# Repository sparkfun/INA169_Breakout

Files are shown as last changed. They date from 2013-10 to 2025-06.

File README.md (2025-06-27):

SparkFun INA169 Current Sensing Breakout
===============

[INA169 Current Sense Breakout Board  
*INA169 Current Sense Breakout Board (SEN-12040)*](https://www.sparkfun.com/products/12040)

High-side current sense breakout board. [The datasheet can be found here.](http://www.ti.com/lit/ds/symlink/ina169.pdf)

This part was created in Eagle v6.0.0. Example sketches were created in Arduino v1.0.5.

Repository Contents
-------------------

* **/Firmware** - Example Arduino sketches
* **/Hardware** - All Eagle design files (.brd, .sch, .STL)
* **/Production** - Test bed files and production panel files

Documentation
-------------------
* **[Hookup Guide](https://learn.sparkfun.com/tutorials/ina169-breakout-board-hookup-guide)**

Version History
---------------
* **v1.0** Initial release

License Information
-------------------
The hardware is released under [Creative Commons Share-alike 3.0](http://creativecommons.org/licenses/by-sa/3.0/).  
All other code is open source so please feel free to do anything you want with it; you buy me a beer if you use this and we meet someday ([Beerware license](http://en.wikipedia.org/wiki/Beerware)).

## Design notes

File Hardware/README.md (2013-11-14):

# What Are these Files?

The .sch and .brd files hare are Eagle CAD schematic and PCB design files.

These files were created with Eagle 6.0.0, you'll need Eagle 6.0 or later to open them up. There is a free, lite, version of Eagle available from [cadsoftusa.com](cadsoftusa.com).

# License

This product is open source! These Eagle files are released under the Creative Commons Share-Alike Attribution license ([CC BY-SA 3.0](http://creativecommons.org/licenses/by-sa/3.0/us/)).

Please use, reuse, and modify these files as you see fit. Please maintain attribution and release anything derivative under the same license.

- Your friends at SparkFun.

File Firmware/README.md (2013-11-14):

* INA169_Arduino_Example - Simple sketch showing how to use the INA169 to measure current through an LED

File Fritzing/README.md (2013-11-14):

* Fritzing diagram showing the INA169 Breakout Board connected to an [Arduino Uno](https://www.sparkfun.com/products/11021)
* The subfolder contains the source files for Fritzing diagrams for the INA169 Breakout Board.

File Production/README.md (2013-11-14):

These are the production files SparkFun uses for printing PCBs, as well as the Eagle files for our test beds.

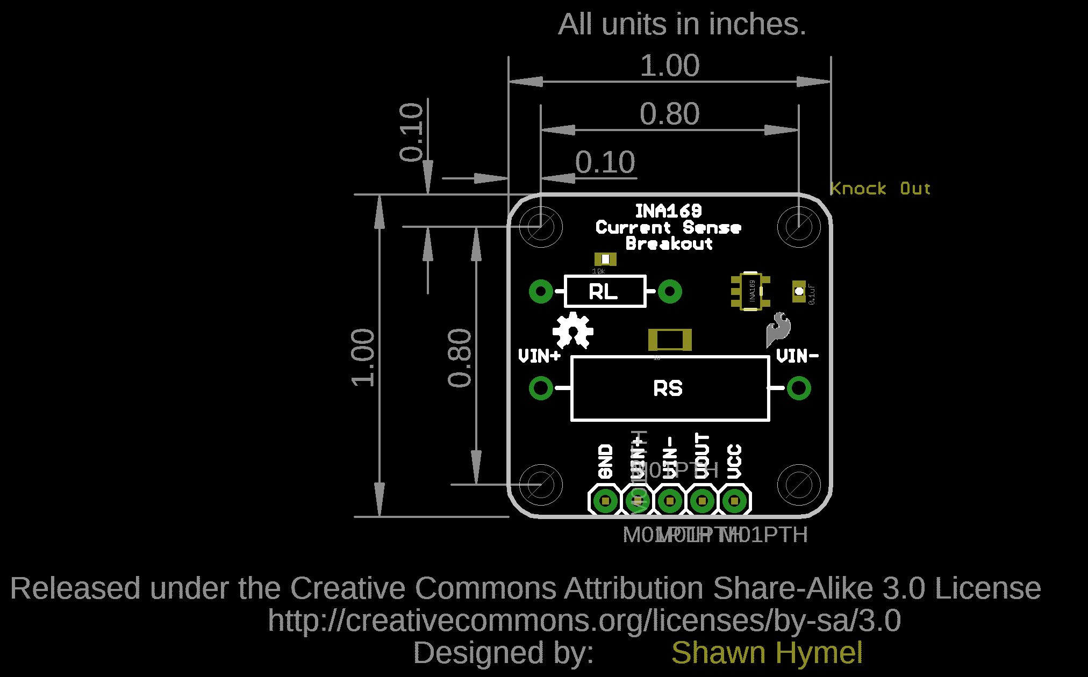
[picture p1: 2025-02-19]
Hardware/SEN-12040_INA169_Current_Sense_Breakout_Board_Dimensions.png

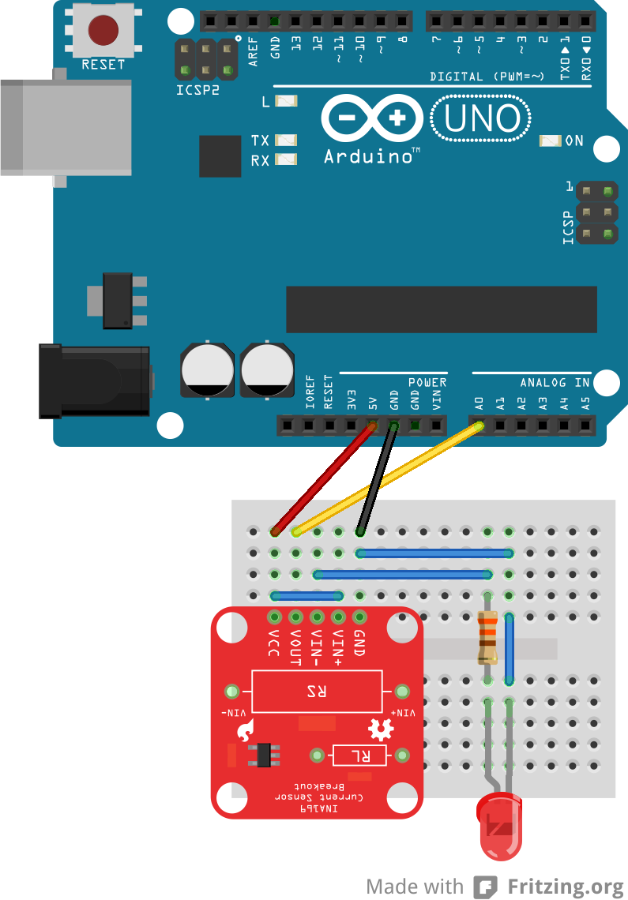
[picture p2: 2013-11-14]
Fritzing/INA169_Arduino_Example.png

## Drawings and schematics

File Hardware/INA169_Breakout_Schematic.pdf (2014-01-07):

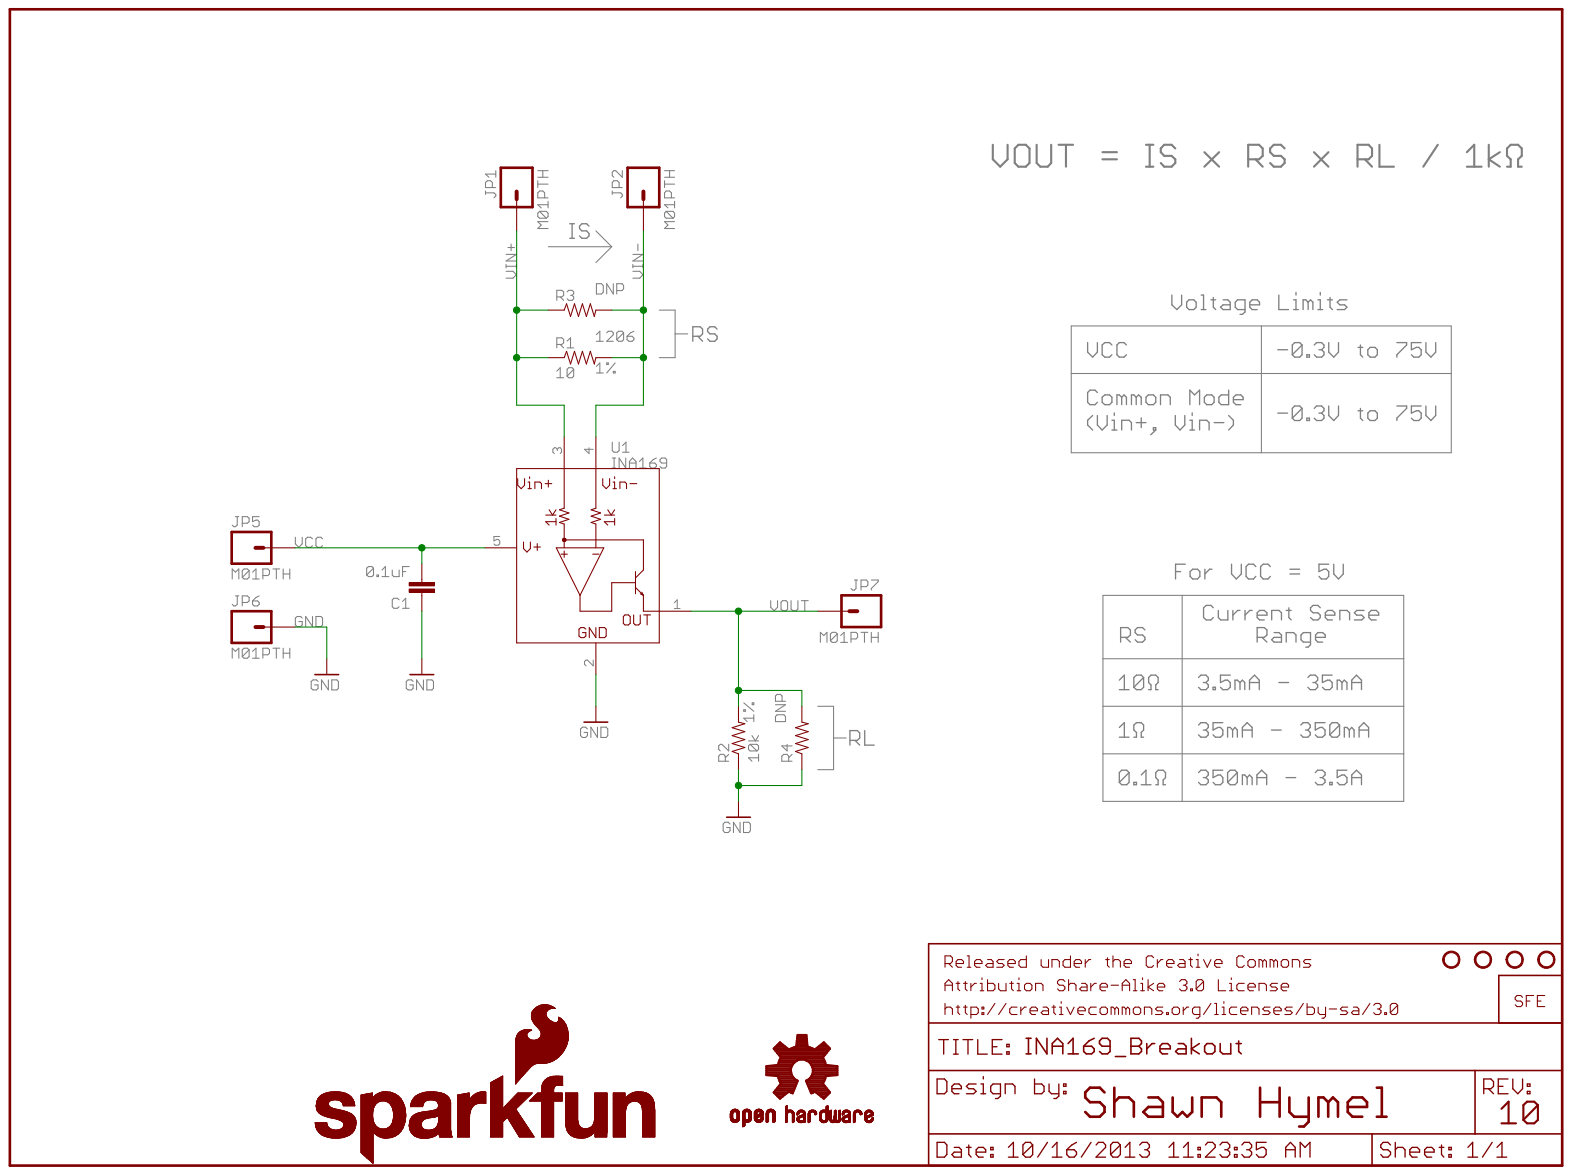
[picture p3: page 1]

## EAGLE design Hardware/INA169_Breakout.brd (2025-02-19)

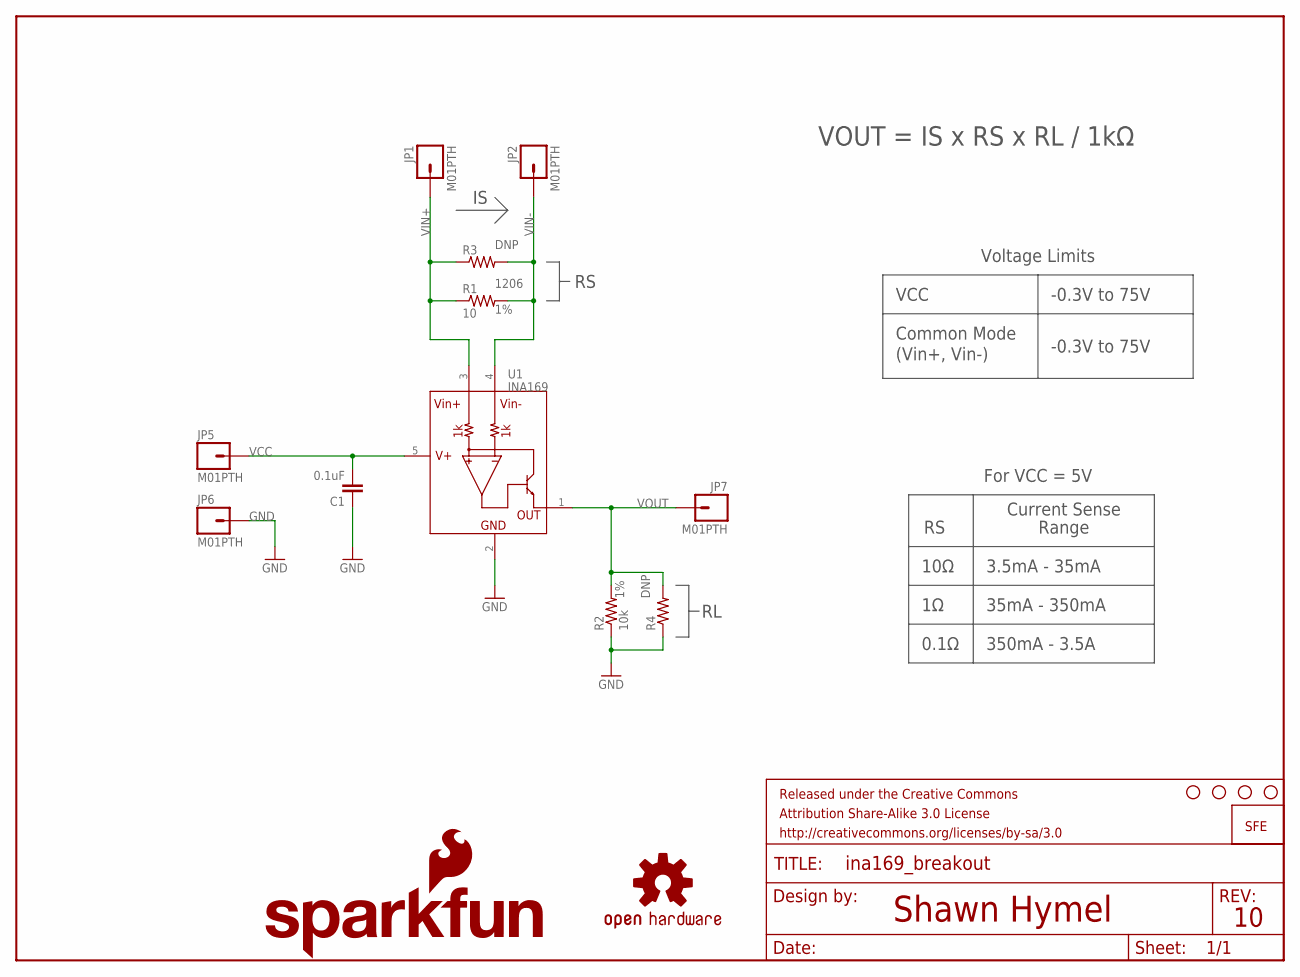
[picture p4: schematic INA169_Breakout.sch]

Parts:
C1: 0.1uF; 0603-CAP
FRAME1: FRAME-LETTER; CREATIVE_COMMONS
JP1, JP2, JP5, JP6, JP7: M01PTH; 1X01
LOGO1: SFE_LOGO_NAME_FLAME.1_INCH; SFE_LOGO_NAME_FLAME_.1
LOGO2: OSHW-LOGOS; OSHW-LOGO-S
LOGO3: LOGO-SFESK; SFE-LOGO-FLAME
R1: 10; 1206
R2: 10k; 0603-RES
R3: RESISTORPTH-2W; AXIAL-0.8
R4: RESISTORPTH-1/4W; AXIAL-0.4
STANDOFF1, STANDOFF2, STANDOFF3, STANDOFF4: STAND-OFF
U1: INA169; SOT23-5

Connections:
GND: C1.1, JP6.1, R2.1, R4.P$1 (1), U1.2 (GND)
VCC: C1.2, JP5.1, U1.5 (V+)
VIN+: JP1.1, R1.1, R3.P$1 (1), U1.3 (VIN+)
VIN-: JP2.1, R1.2, R3.P$2 (2), U1.4 (VIN-)
VOUT: JP7.1, R2.2, R4.P$2 (2), U1.1 (OUT)

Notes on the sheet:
Shawn Hymel
For VCC = 5V
Range
Current Sense
10Ω
0.1Ω
3.5mA - 35mA
35mA - 350mA
350mA - 3.5A
Voltage Limits
VCC
Common Mode
(Vin+, Vin-)
-0.3V to 75V
VOUT = IS x RS x RL / 1kΩ

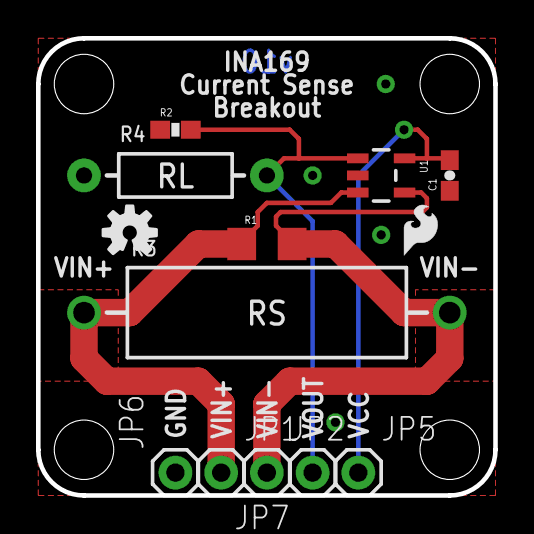
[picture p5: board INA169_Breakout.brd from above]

Board: 2 copper layers, 25.4 x 25.4 mm, 19 parts (1 on the bottom side), 5 nets.

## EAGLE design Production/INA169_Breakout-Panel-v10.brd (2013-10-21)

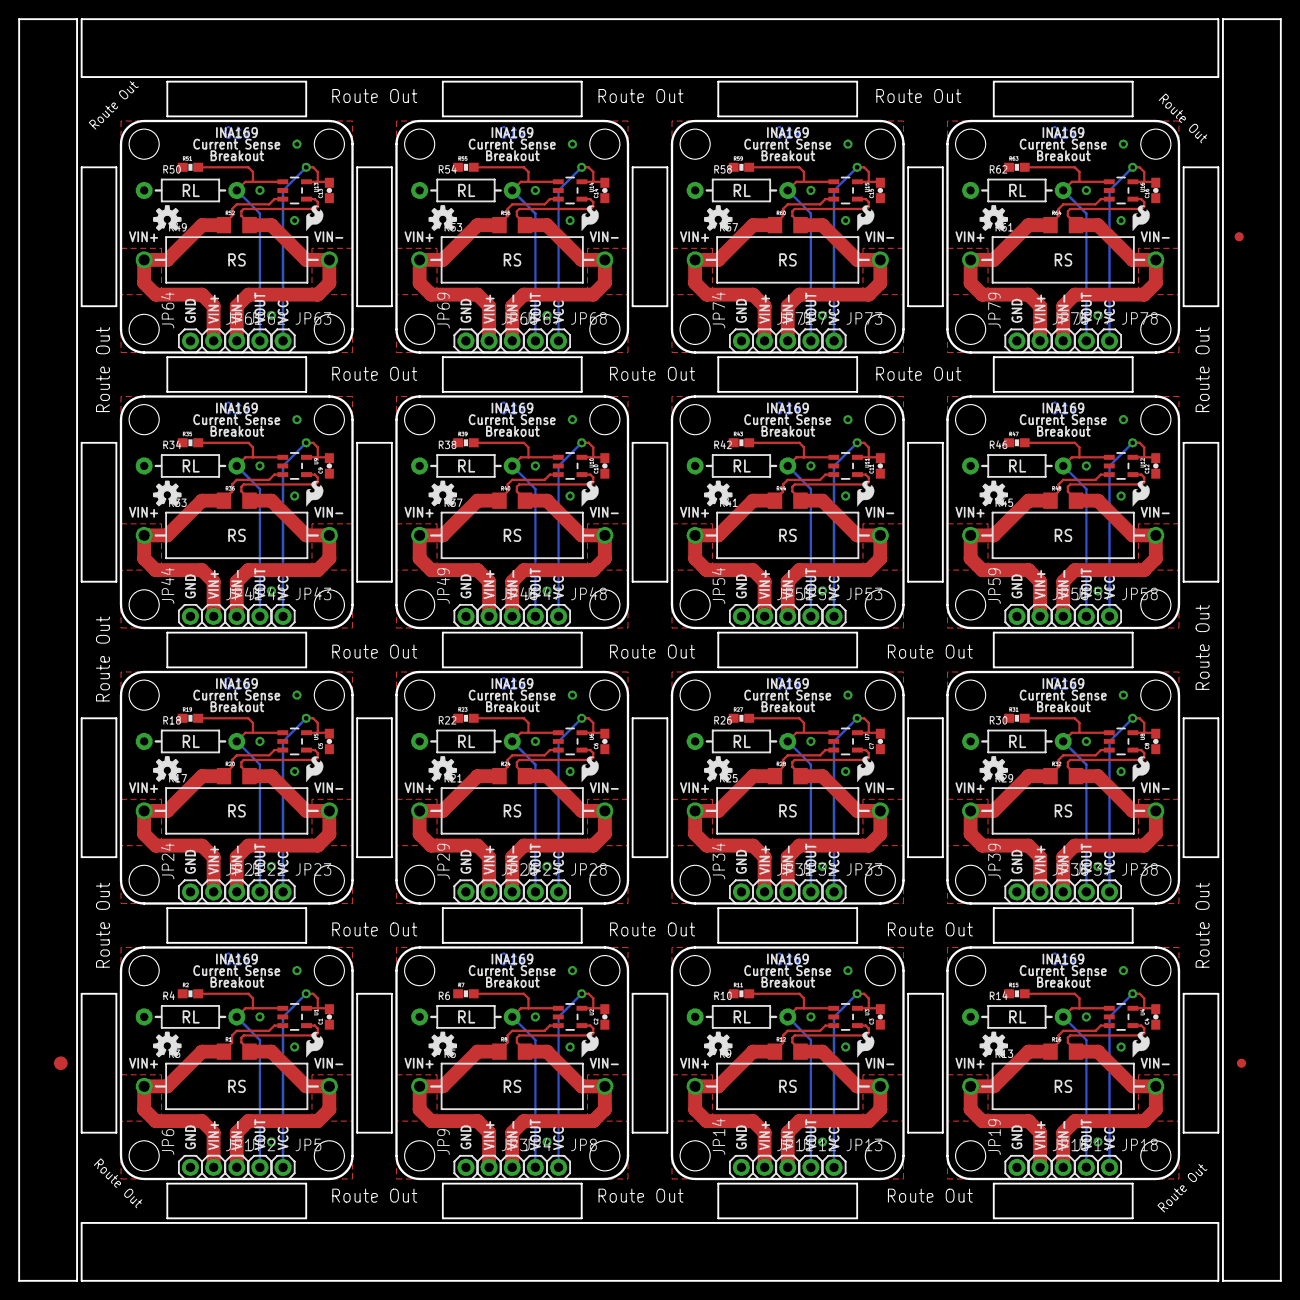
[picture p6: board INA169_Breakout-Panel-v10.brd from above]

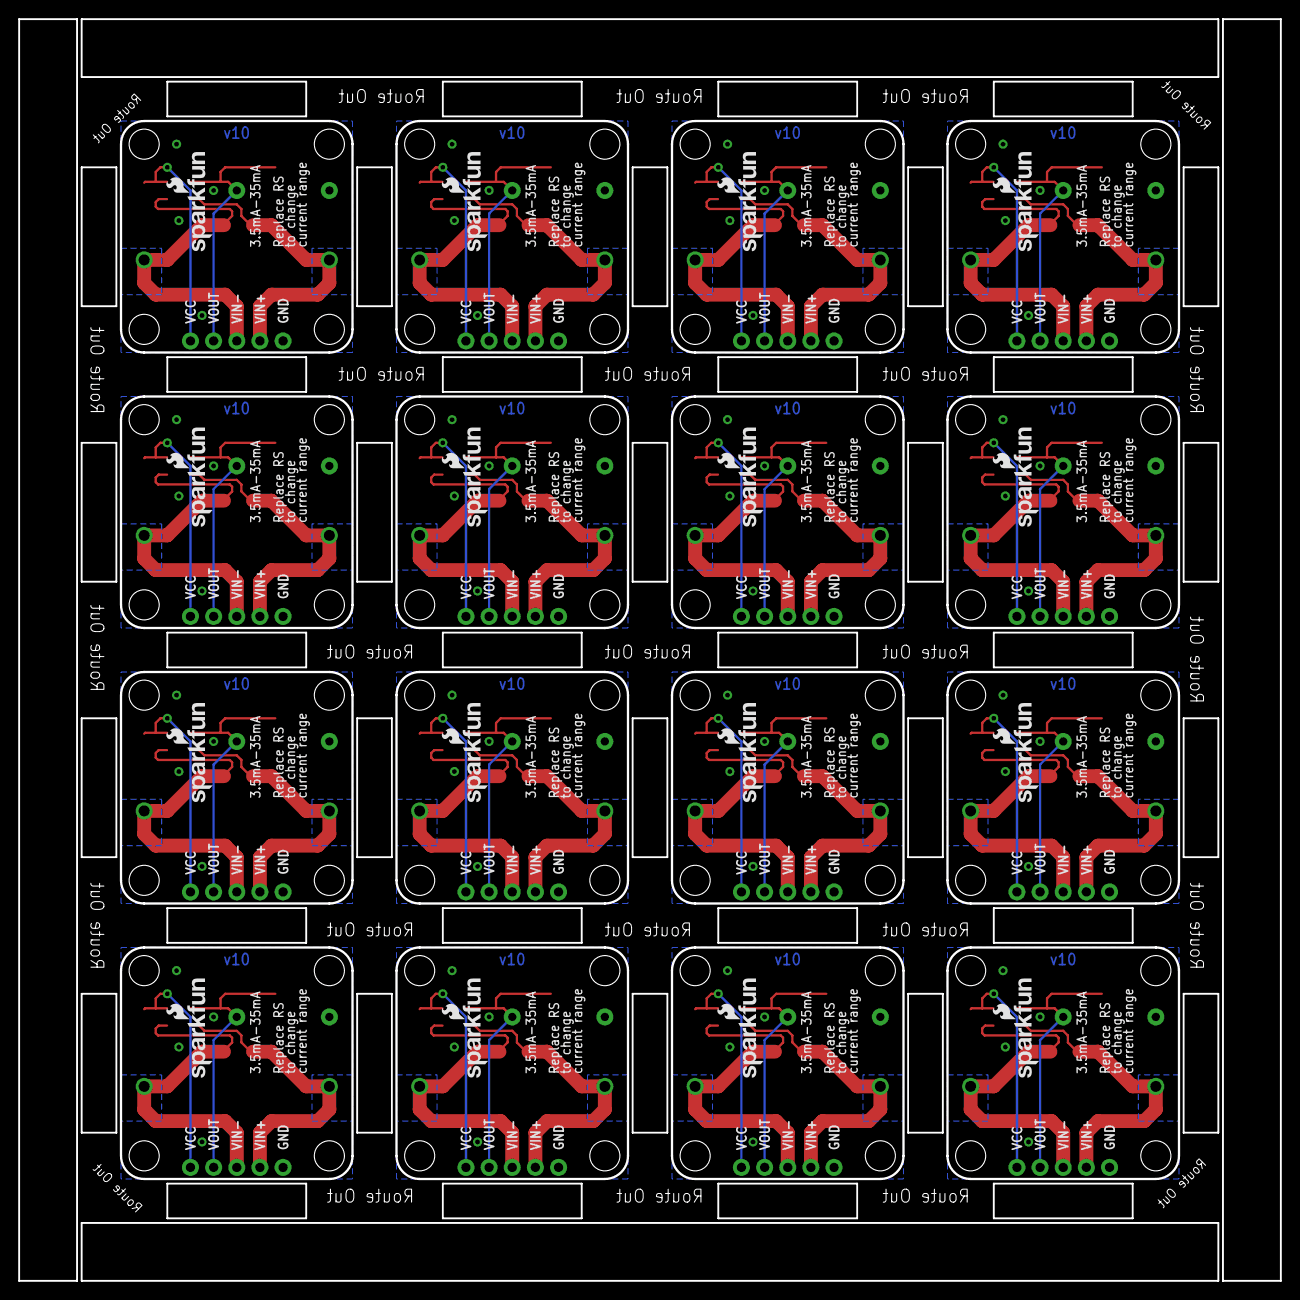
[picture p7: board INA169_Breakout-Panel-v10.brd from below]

Board: 2 copper layers, 138.4 x 138.4 mm, 291 parts (16 on the bottom side), 80 nets.

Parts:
C1, C2, C3, C4, C5, C6, C7, C8, C9, C10, C11, C12, C13, C14, C15, C16: 0.1uF; 0603-CAP
E$1: FIDUCIAL-1.5X3
E$4, E$5: FIDUCIAL-1X2
JP1, JP2, JP3, JP4, JP5, JP6, JP7, JP8, JP9, JP10, JP11, JP12, JP13, JP14, JP15, JP16, JP17, JP18, JP19, JP20, JP21, JP22, JP23, JP24, JP25, JP26, JP27, JP28, JP29, JP30, JP31, JP32, JP33, JP34, JP35, JP36, JP37, JP38, JP39, JP40, JP41, JP42, JP43, JP44, JP45, JP46, JP47, JP48, JP49, JP50, JP51, JP52, JP53, JP54, JP55, JP56, JP57, JP58, JP59, JP60, JP61, JP62, JP63, JP64, JP65, JP66, JP67, JP68, JP69, JP70, JP71, JP72, JP73, JP74, JP75, JP76, JP77, JP78, JP79, JP80: M01PTH; 1X01
LOGO1, LOGO4, LOGO7, LOGO10, LOGO13, LOGO16, LOGO19, LOGO22, LOGO25, LOGO28, LOGO31, LOGO34, LOGO37, LOGO40, LOGO43, LOGO46: SFE_LOGO_NAME_FLAME.1_INCH; SFE_LOGO_NAME_FLAME_.1
LOGO2, LOGO5, LOGO8, LOGO11, LOGO14, LOGO17, LOGO20, LOGO23, LOGO26, LOGO29, LOGO32, LOGO35, LOGO38, LOGO41, LOGO44, LOGO47: OSHW-LOGOS; OSHW-LOGO-S
LOGO3, LOGO6, LOGO9, LOGO12, LOGO15, LOGO18, LOGO21, LOGO24, LOGO27, LOGO30, LOGO33, LOGO36, LOGO39, LOGO42, LOGO45, LOGO48: LOGO-SFESK; SFE-LOGO-FLAME
R1, R8, R12, R16, R20, R24, R28, R32, R36, R40, R44, R48, R52, R56, R60, R64: 10; 1206
R2, R7, R11, R15, R19, R23, R27, R31, R35, R39, R43, R47, R51, R55, R59, R63: 10k; 0603-RES
R3, R5, R9, R13, R17, R21, R25, R29, R33, R37, R41, R45, R49, R53, R57, R61: AXIAL-0.8
R4, R6, R10, R14, R18, R22, R26, R30, R34, R38, R42, R46, R50, R54, R58, R62: AXIAL-0.4
STANDOFF1, STANDOFF2, STANDOFF3, STANDOFF4, STANDOFF5, STANDOFF6, STANDOFF7, STANDOFF8, STANDOFF9, STANDOFF10, STANDOFF11, STANDOFF12, STANDOFF13, STANDOFF14, STANDOFF15, STANDOFF16, STANDOFF17, STANDOFF18, STANDOFF19, STANDOFF20, STANDOFF21, STANDOFF22, STANDOFF23, STANDOFF24, STANDOFF25, STANDOFF26, STANDOFF27, STANDOFF28, STANDOFF29, STANDOFF30, STANDOFF31, STANDOFF32, STANDOFF33, STANDOFF34, STANDOFF35, STANDOFF36, STANDOFF37, STANDOFF38, STANDOFF39, STANDOFF40, STANDOFF41, STANDOFF42, STANDOFF43, STANDOFF44, STANDOFF45, STANDOFF46, STANDOFF47, STANDOFF48, STANDOFF49, STANDOFF50, STANDOFF51, STANDOFF52, STANDOFF53, STANDOFF54, STANDOFF55, STANDOFF56, STANDOFF57, STANDOFF58, STANDOFF59, STANDOFF60, STANDOFF61, STANDOFF62, STANDOFF63, STANDOFF64: STAND-OFF
U1, U2, U3, U4, U5, U6, U7, U8, U9, U10, U11, U12, U13, U14, U15, U16: INA169; SOT23-5

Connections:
GND: C1.1, JP6.1, R2.1, R4.P$1, U1.2
GND1: C2.1, JP9.1, R6.P$1, R7.1, U2.2
GND2: C3.1, JP14.1, R10.P$1, R11.1, U3.2
GND3: C4.1, JP19.1, R14.P$1, R15.1, U4.2
GND4: C5.1, JP24.1, R18.P$1, R19.1, U5.2
GND5: C6.1, JP29.1, R22.P$1, R23.1, U6.2
GND6: C7.1, JP34.1, R26.P$1, R27.1, U7.2
GND7: C8.1, JP39.1, R30.P$1, R31.1, U8.2
GND8: C9.1, JP44.1, R34.P$1, R35.1, U9.2
GND9: C10.1, JP49.1, R38.P$1, R39.1, U10.2
GND10: C11.1, JP54.1, R42.P$1, R43.1, U11.2
GND11: C12.1, JP59.1, R46.P$1, R47.1, U12.2
GND12: C13.1, JP64.1, R50.P$1, R51.1, U13.2
GND13: C14.1, JP69.1, R54.P$1, R55.1, U14.2
GND14: C15.1, JP74.1, R58.P$1, R59.1, U15.2
GND15: C16.1, JP79.1, R62.P$1, R63.1, U16.2
VCC: C1.2, JP5.1, U1.5
VCC1: C2.2, JP8.1, U2.5
VCC2: C3.2, JP13.1, U3.5
VCC3: C4.2, JP18.1, U4.5
VCC4: C5.2, JP23.1, U5.5
VCC5: C6.2, JP28.1, U6.5
VCC6: C7.2, JP33.1, U7.5
VCC7: C8.2, JP38.1, U8.5
VCC8: C9.2, JP43.1, U9.5
VCC9: C10.2, JP48.1, U10.5
VCC10: C11.2, JP53.1, U11.5
VCC11: C12.2, JP58.1, U12.5
VCC12: C13.2, JP63.1, U13.5
VCC13: C14.2, JP68.1, U14.5
VCC14: C15.2, JP73.1, U15.5
VCC15: C16.2, JP78.1, U16.5
VIN+: JP1.1, R1.1, R3.P$1, U1.3
VIN+1: JP3.1, R5.P$1, R8.1, U2.3
VIN+2: JP11.1, R9.P$1, R12.1, U3.3
VIN+3: JP16.1, R13.P$1, R16.1, U4.3
VIN+4: JP21.1, R17.P$1, R20.1, U5.3
VIN+5: JP26.1, R21.P$1, R24.1, U6.3
VIN+6: JP31.1, R25.P$1, R28.1, U7.3
VIN+7: JP36.1, R29.P$1, R32.1, U8.3
VIN+8: JP41.1, R33.P$1, R36.1, U9.3
VIN+9: JP46.1, R37.P$1, R40.1, U10.3
VIN+10: JP51.1, R41.P$1, R44.1, U11.3
VIN+11: JP56.1, R45.P$1, R48.1, U12.3
VIN+12: JP61.1, R49.P$1, R52.1, U13.3
VIN+13: JP66.1, R53.P$1, R56.1, U14.3
VIN+14: JP71.1, R57.P$1, R60.1, U15.3
VIN+15: JP76.1, R61.P$1, R64.1, U16.3
VIN-: JP2.1, R1.2, R3.P$2, U1.4
VIN-1: JP4.1, R5.P$2, R8.2, U2.4
VIN-2: JP12.1, R9.P$2, R12.2, U3.4
VIN-3: JP17.1, R13.P$2, R16.2, U4.4
VIN-4: JP22.1, R17.P$2, R20.2, U5.4
VIN-5: JP27.1, R21.P$2, R24.2, U6.4
VIN-6: JP32.1, R25.P$2, R28.2, U7.4
VIN-7: JP37.1, R29.P$2, R32.2, U8.4
VIN-8: JP42.1, R33.P$2, R36.2, U9.4
VIN-9: JP47.1, R37.P$2, R40.2, U10.4
VIN-10: JP52.1, R41.P$2, R44.2, U11.4
VIN-11: JP57.1, R45.P$2, R48.2, U12.4
VIN-12: JP62.1, R49.P$2, R52.2, U13.4
VIN-13: JP67.1, R53.P$2, R56.2, U14.4
VIN-14: JP72.1, R57.P$2, R60.2, U15.4
VIN-15: JP77.1, R61.P$2, R64.2, U16.4
VOUT: JP7.1, R2.2, R4.P$2, U1.1
VOUT1: JP10.1, R6.P$2, R7.2, U2.1
VOUT2: JP15.1, R10.P$2, R11.2, U3.1
VOUT3: JP20.1, R14.P$2, R15.2, U4.1
VOUT4: JP25.1, R18.P$2, R19.2, U5.1
VOUT5: JP30.1, R22.P$2, R23.2, U6.1
VOUT6: JP35.1, R26.P$2, R27.2, U7.1
VOUT7: JP40.1, R30.P$2, R31.2, U8.1
VOUT8: JP45.1, R34.P$2, R35.2, U9.1
VOUT9: JP50.1, R38.P$2, R39.2, U10.1
VOUT10: JP55.1, R42.P$2, R43.2, U11.1
VOUT11: JP60.1, R46.P$2, R47.2, U12.1
VOUT12: JP65.1, R50.P$2, R51.2, U13.1
VOUT13: JP70.1, R54.P$2, R55.2, U14.1
VOUT14: JP75.1, R58.P$2, R59.2, U15.1
VOUT15: JP80.1, R62.P$2, R63.2, U16.1

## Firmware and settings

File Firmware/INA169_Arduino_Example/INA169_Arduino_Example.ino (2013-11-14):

/*
 11-14-2013
 SparkFun Electronics 2013
 Shawn Hymel

 This code is public domain but you buy me a beer if you use this 
 and we meet someday (Beerware license).

 Description:

 This sketch shows how to use the SparkFun INA169 Breakout
 Board. As current passes through the shunt resistor (Rs), a
 voltage is generated at the Vout pin. Use an analog read and
 some math to determine the current. The current value is
 displayed through the Serial Monitor.

 Hardware connections:
 
 Uno Pin    INA169 Board    Function
 
 +5V        VCC             Power supply
 GND        GND             Ground
 A0         VOUT            Analog voltage measurement

 VIN+ and VIN- need to be connected inline with the positive
 DC power rail of a load (e.g. an Arduino, an LED, etc.).
 
 */

// Constants
const int SENSOR_PIN = A0;  // Input pin for measuring Vout
const int RS = 10;          // Shunt resistor value (in ohms)
const int VOLTAGE_REF = 5;  // Reference voltage for analog read

// Global Variables
float sensorValue;   // Variable to store value from analog read
float current;       // Calculated current value

void setup() {
  
  // Initialize serial monitor
  Serial.begin(9600);
  
}

void loop() {
  
  // Read a value from the INA169 board
  sensorValue = analogRead(SENSOR_PIN);
  
  // Remap the ADC value into a voltage number (5V reference)
  sensorValue = (sensorValue * VOLTAGE_REF) / 1023;
  
  // Follow the equation given by the INA169 datasheet to
  // determine the current flowing through RS. Assume RL = 10k
  // Is = (Vout x 1k) / (RS x RL)
  current = sensorValue / (10 * RS);
  
  // Output value (in amps) to the serial monitor to 3 decimal
  // places
  Serial.print(current, 3);
  Serial.println(" A");
  
  // Delay program for a few milliseconds
  delay(500);
  
}

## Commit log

2013-08-20 Added prototype board files for review
    [INA169_Breakout.brd, INA169_Breakout.sch]
2013-08-27 Fixed changes from board review. Ready for prototype.
    [INA169_Breakout.brd, INA169_Breakout.sch]
2013-10-01 Fixed silkscreen. Ready for review.
    [INA169_Breakout.brd, INA169_Breakout.sch]
2013-10-16 Added tables on sch, added pads on brd
    [INA169_Breakout.brd, INA169_Breakout.sch]
2013-10-16 Changed to smaller SFE logo on brd
    [INA169_Breakout.brd, INA169_Breakout.sch]
2013-10-21 Created Panel
    [INA169_Breakout-Panel-v10.brd]
2013-11-13 Added Arduino example to Firmware
2013-11-14 Updated READMEs, added Fritzing part, corrected comments in example sketch
    [INA169_Arduino_Example.fzz, INA169_Breakout-Panel-v10.brd]
2014-01-07 Re-printed pdf version of schematic
2025-02-19 Add Board Dimensions
    [INA169_Breakout.brd, INA169_Breakout.sch]

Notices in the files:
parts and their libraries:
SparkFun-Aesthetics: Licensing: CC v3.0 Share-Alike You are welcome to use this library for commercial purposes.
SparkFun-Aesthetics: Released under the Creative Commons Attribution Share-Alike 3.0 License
